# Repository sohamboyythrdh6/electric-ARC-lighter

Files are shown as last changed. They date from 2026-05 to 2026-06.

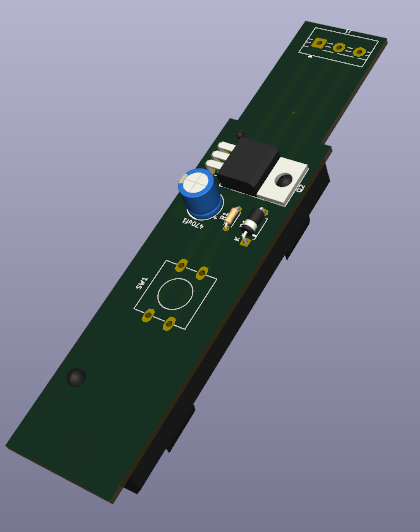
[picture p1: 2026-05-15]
ASSETS/Screenshot 2026-05-15 214929.png

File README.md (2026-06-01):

# electric-ARC-lighter
an electric lighter is a very useful project. which can be use for start a fire or ignite our gas stove .it's not like other lighters because it is charge by a type c charger and it dosen't need to refill gas .just charge and whenever need just press the switch and use.this project will teach us how crazy and dangerous can a hihg voltage transformer is which can turn 5 volt into 1000 of volts.

to build this lighter you jest need to collect the components pcb and those 3d models then connect all the parts to the pcb using solder later confirming everypart is in correct place put everything in the case and glued it and then it will be ready to use .But before using full charge this.





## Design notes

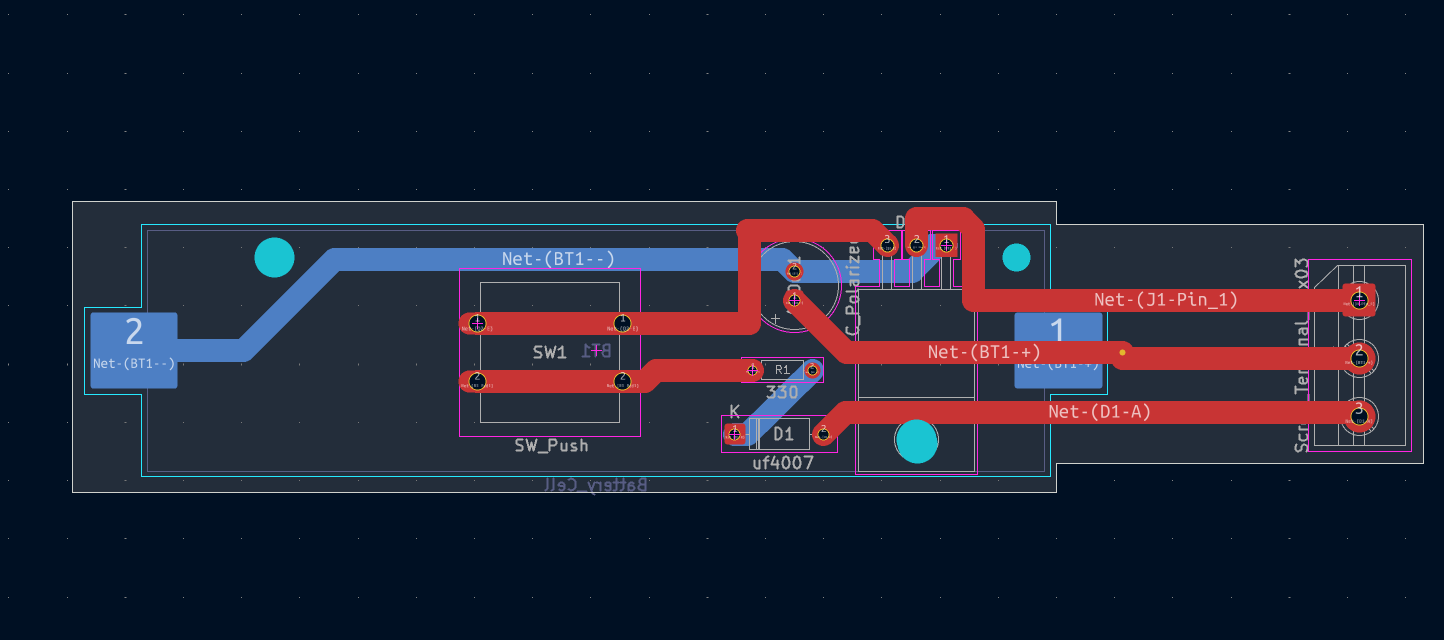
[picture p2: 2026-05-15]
ASSETS/Screenshot 2026-05-15 214209.png

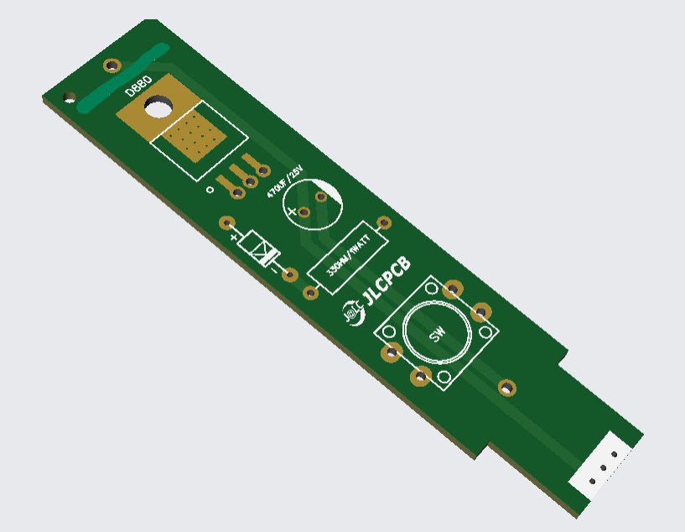
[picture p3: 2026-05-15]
ASSETS/Screenshot 2026-05-15 215654.png

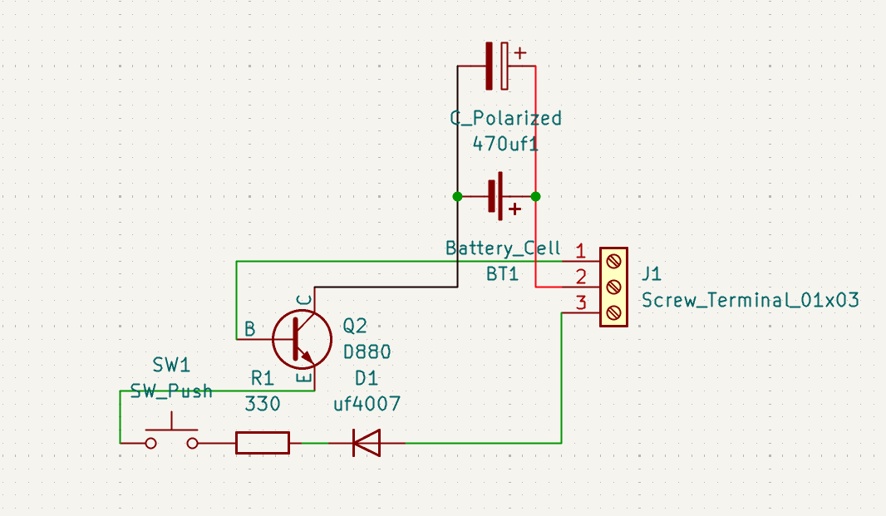
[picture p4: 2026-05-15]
ASSETS/Screenshot 2026-05-15 214145.png

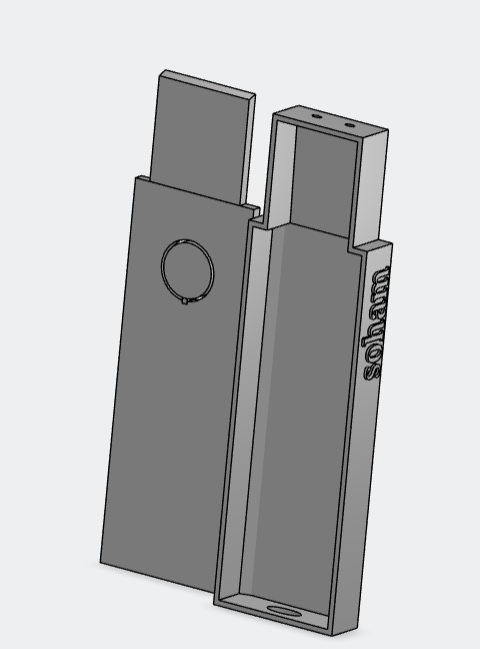
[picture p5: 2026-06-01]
ASSETS/Screenshot 2026-06-01 223140.png

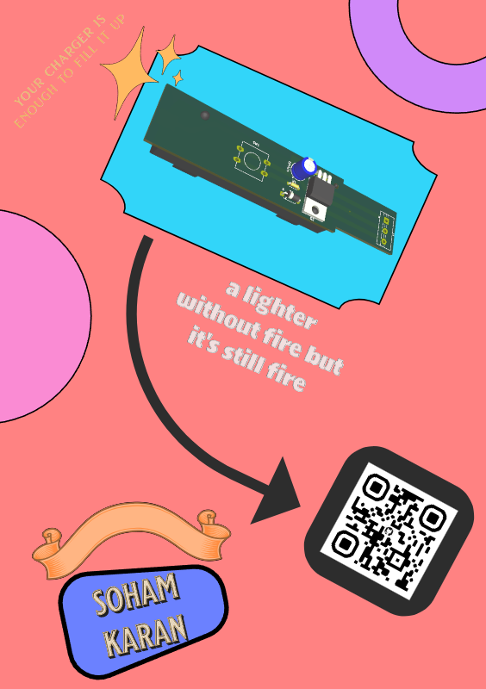
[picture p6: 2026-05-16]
zine.png

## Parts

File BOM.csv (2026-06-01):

name | quantity | link | price(dollar) | use
12x12mm Tactile Push Button | 1 | https://makerbazar.in/products/tactile-push-button?variant=47433066184944 | 0.47 | for turning on and off
3.7v 400 mah lipo battery | 1 | https://robu.in/product/400mah-pcm-protected-micro-li-po-battery-2/ | 2.87 | for power the lighter
tp4056 battery charging module | 1 | https://robu.in/product/tp4056-1a-li-ion-battery-charging-board-micro-usb-with-current-protection-type-c-connector/ | 0.17 | to charge the battery
330 ohm resstor | 1 | https://makerbazar.in/products/0-5-watt-dip-resistors-through-hole-resistance?variant=48049213636848 | 20 | for limoting the current
1N4007 diode | 1 | https://makerbazar.in/products/dip-rectifier-diode-through-hole?variant=46915109421296 | 0.14 | for protecting the circuit flyback
High Voltage Arc Generator | 1 | https://robu.in/product/15kv-high-voltage-generator-arc-ignition-inverter-step-up-boost-coil-module/ | 1.16 | for genarate arc
470uf 50v capasitor | 1 | https://makerbazar.in/products/electrolytic-capacitor-through-hole?variant=48721342791920 | 0.16 | store current and give stabel voltage
D880 transistor | 1 | https://componentstree.com/product/2sd880-y-d880-y-to-220-60v-3a-40w-audio-amplifier-switching-fsc/ | 0.26 | for switching
custom pcb | 1 | https://cart.jlcpcb.com/shopcart/cart/ | 2.1 | connect all components
custom case | 1 | https://cart.jlcpcb.com/shopcart/cart/ | 1.6 | for cover it
delivery charges | 4 |  | 15

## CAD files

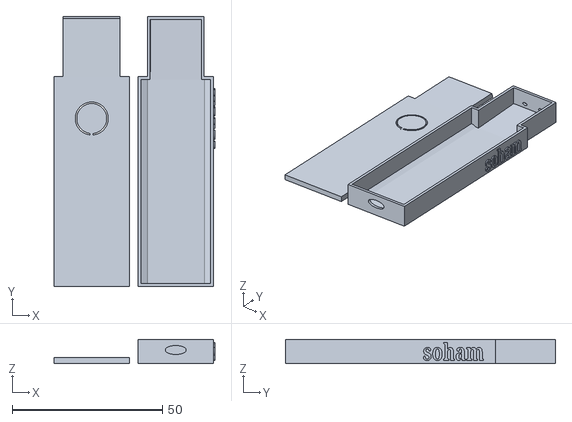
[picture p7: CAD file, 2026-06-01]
3D MODEL.stl
53.5 x 90.0 x 8.00

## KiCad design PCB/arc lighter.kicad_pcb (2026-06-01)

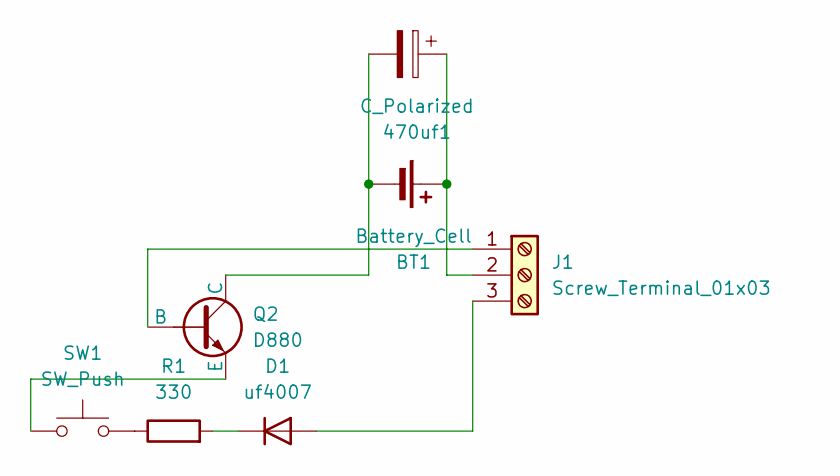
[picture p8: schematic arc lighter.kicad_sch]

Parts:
470uf1: C_Polarized; CP_Radial_D7.5mm_P2.50mm
BT1: Battery_Cell; PinSocket_1x02_P2.00mm_Vertical
D1: uf4007; D_A-405_P7.62mm_Horizontal
J1: Screw_Terminal_01x03; TerminalBlock_MaiXu_MX126-5.0-03P_1x03_P5.00mm
Q2: D880; TO-220-3_Horizontal_TabDown
R1: 330; R_Axial_DIN0204_L3.6mm_D1.6mm_P5.08mm_Horizontal
SW1: SW_Push; SW_PUSH-12mm

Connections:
unnamed: 470uf1.1, BT1.1 (+), J1.2
unnamed: 470uf1.2, BT1.2 (-), Q2.1 (C)
unnamed: D1.2 (A), J1.3
unnamed: D1.1 (K), R1.2
unnamed: J1.1, Q2.2 (B)
unnamed: Q2.3 (E), SW1.1
unnamed: R1.1, SW1.2

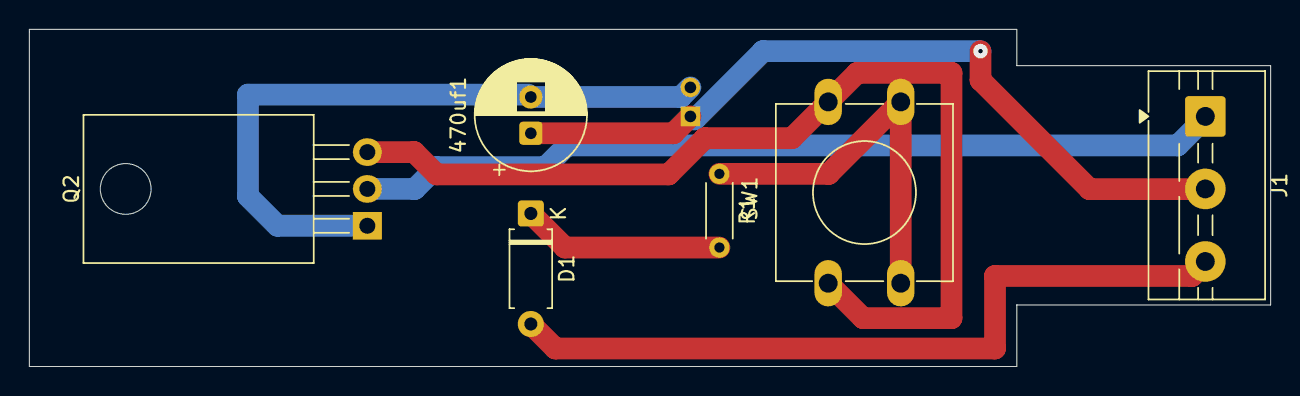
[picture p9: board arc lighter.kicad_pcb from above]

Board: 2 copper layers, 85.6 x 23.2 mm, 7 parts (1 on the bottom side), 7 nets.
